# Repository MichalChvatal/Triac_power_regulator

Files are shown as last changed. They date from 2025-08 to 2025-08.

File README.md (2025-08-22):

# AVR Triac Regulator (ATtiny13)

---

## ⚠️ Safety Disclaimer

This project involves **AC mains voltage**, which is **extremely dangerous** and can cause **serious injury or death**.  

By using this project, you accept **full responsibility** for any accidents, injuries, or damages. The author is **not liable** for any consequences resulting from its use.  

**Important Safety Guidelines:**
- Always use insulated tools and protective equipment.
- Work with a qualified professional if you are inexperienced with mains circuits.
- Use galvanic isolation (optotriacs/optocouplers) wherever possible.
- **Do not proceed** if you are unfamiliar with handling high voltage.

---

## Project Overview

This project implements a **power regulator for universal commutator motors** (motors with brushes) and resistive loads (e.g., light bulbs and heating elements) using the **ATtiny13** microcontroller.  
It provides **0–100% power control** through **phase-angle control of a triac** with **AC mains zero-cross detection**.

⚠️ **Warning:** The circuit connects directly to **230 V mains**. Extreme caution is required during assembly and testing.

---

## ✨ Features
- Measurement of the delay between zero-crossing and triac triggering.
- Adjustable firing angle using a potentiometer (or DIP switch).
- Generation of a trigger pulse for the optotriac in every half cycle.
- Motor power control from **fully OFF (0%)** to **fully ON (100%)**.

---

## 🧩 Components

### Triac driver (optotriac)
Must be of the **random-phase type** (no built-in zero-cross detection), e.g.:
- `MOC3021`
- `MOC3010`

### Zero-cross detector
The output must be a **rectangular pulse signal** for reliable edge detection by the MCU, e.g.:
- `H11L1` (recommended)

If using slower optocouplers such as `4N35`, you must add a **Schmitt trigger** circuit to clean up the signal.

### Microcontroller
- `ATtiny13` (or alternatively `ATmega8`)

### Firing angle adjustment
- **Potentiometer** (connected to ADC input)  
- or **DIP switch** (digital inputs)

---

## ⚡ Safety notes
- This regulator is suitable only for **universal commutator motors (brush motors)** and **resistive loads** (e.g., light bulbs and heating elements).
- It is **not suitable for asynchronous (induction) motors**.  
- The motor must **not** have its own built-in electronic regulation.  
- The motor must use **series excitation**.

---

## 🛠️ Project directory structure

- **HW/** – Eagle PCB design files (.sch, .brd)
- **SW/**  - Atmel Studio project files (.cproj, .atsln), Doxyfile
  - **src/** – Source files (.c)
  - **inc/** – Header files (.h)
  - **docs/** – Generated documentation (Doxygen)

---

## ⚙️ Fuse and clock configuration

- Set fuses for **internal oscillator 4.8 MHz**:  
  - **Low fuse:** `0x79`  
  - **High fuse:** `0xFF`  
- ⚠️ **Calibration is required** – see ATtiny13 datasheet for details.  
- Note: `clk I/O` = `clk CPU`. The difference is that during sleep mode, **I/O clocks are disabled**, while CPU/peripheral clocks may continue to run.

--- 

## 🔧 Building the Project
To build the project, launch the **Regulator.atsln** file with **Microchip Studio (version 7.0.2594)**.

- From the menu bar, select Build > Build Solution.
-  Alternatively, use the shortcut F7.

The output files will be located in the project's **Debug** or **Release** folder.

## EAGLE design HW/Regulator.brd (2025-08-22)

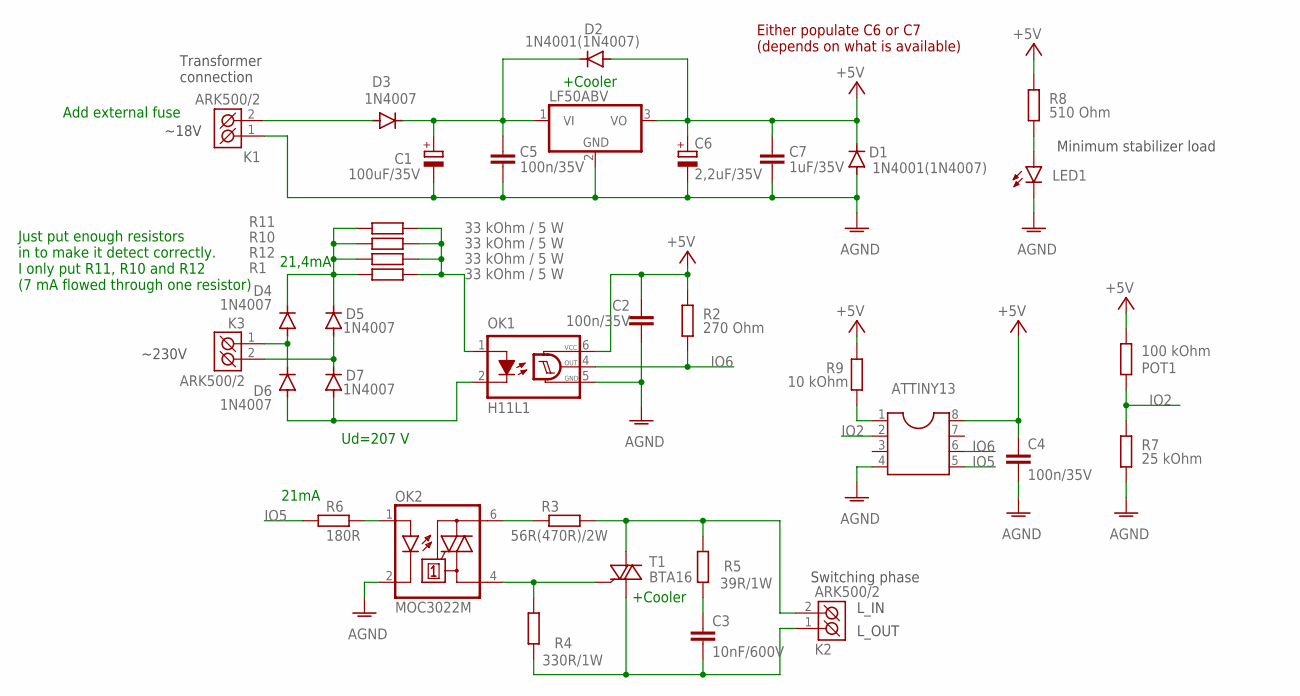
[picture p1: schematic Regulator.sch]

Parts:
ATTINY13: DIL8S; SOCKET-08
C1: 100uF/35V; E3,5-8
C2, C4, C5: 100n/35V; C050-025X075
C3: 10nF/600V; C025-030X050
C6: 2,2uF/35V; E2-4
C7: 1uF/35V; C050-025X075
D1, D2: 1N4001(1N4007); DO41-7.6
D3, D4, D5, D6, D7: 1N4007; DO41-7.6
K1, K2, K3: ARK500/2
LED1: LED5MM
OK1: H11L1; DIL06
OK2: MOC3022M; DIL06
POT1: 100 kOhm; 0207/10
R1, R10, R11, R12: 33 kOhm / 5 W; 0617V
R2: 270 Ohm; 0207/10
R3: 56R(470R)/2W; 0411/15
R4: 330R/1W; 0411/15
R5: 39R/1W; 0411/15
R6: 180R; 0207/10
R7: 25 kOhm; 0207/10
R8: 510 Ohm; 0207/10
R9: 10 kOhm; 0207/10
ST1: LF50ABV; TO220V
T1: BTA16; TO220BV

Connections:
+5V: ATTINY13.8, C2.1, C4.1, C6.+, C7.1, D1.C, D2.A, OK1.6 (VCC), POT1.1, R2.1, R8.1, R9.1, ST1.3 (VO)
AGND: ATTINY13.4, C1.-, C2.2, C4.2, C5.2, C6.-, C7.2, D1.A, K1.1 (K1), LED1.K (C), OK1.5 (GND), OK2.2 (C), R7.2, ST1.2 (GND)
IO2: ATTINY13.2, POT1.2, R7.1
IO5: ATTINY13.5, R6.1
IO6: ATTINY13.6, OK1.4 (OUT), R2.2
L_IN: K2.2 (K2), R3.2, R5.2, T1.T2 (A2)
L_OUT: C3.2, K2.1 (K1), R4.1, T1.T1 (A1)
unnamed: OK1.1 (A), R1.2, R10.2, R11.2, R12.2
unnamed: D4.A, D6.C, K3.1 (K1)
unnamed: LED1.A, R8.2
unnamed: D3.A, K1.2 (K2)
unnamed: OK2.6 (A2), R3.1
unnamed: D6.A, D7.A, OK1.2 (C)
unnamed: D5.A, D7.C, K3.2 (K2)
unnamed: C1.+, C5.1, D2.C, D3.C, ST1.1 (VI)
unnamed: OK2.1 (A), R6.2
unnamed: C3.1, R5.1
unnamed: OK2.4 (A1), R4.2, T1.G
unnamed: ATTINY13.1, R9.2
unnamed: D4.C, D5.C, R1.1, R10.1, R11.1, R12.1

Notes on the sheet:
Add external fuse
+Cooler
21mA
21,4mA
Either populate C6 or C7 (depends on what is available)
Minimum stabilizer load
L_IN
L_OUT
~18V
Switching phase
Transformer connection
~230V
Ud=207 V
Just put enough resistors in to make it detect correctly. I only put R11, R10 and R12 (7 mA flowed through one resistor)

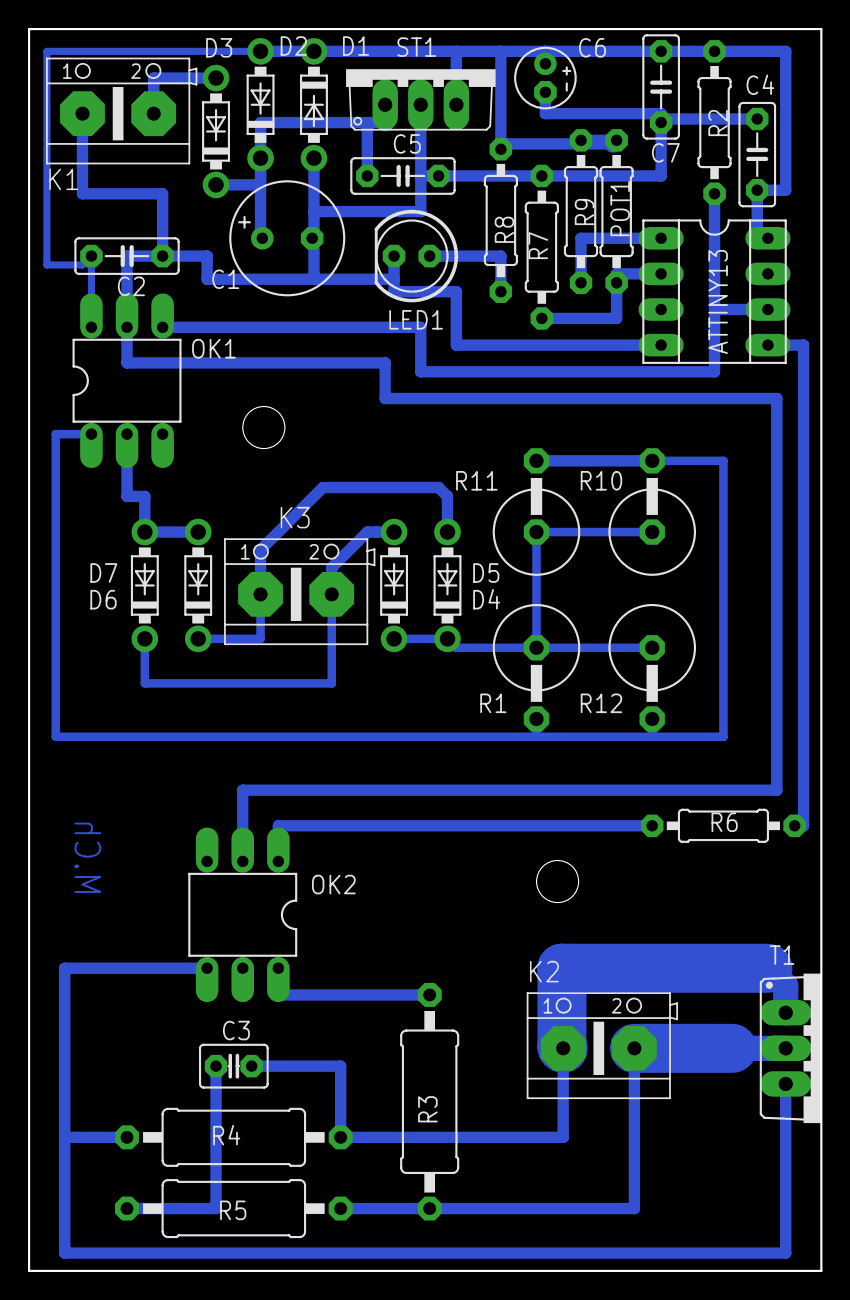
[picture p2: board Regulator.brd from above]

Board: 2 copper layers, 56.5 x 88.6 mm, 36 parts (0 on the bottom side), 20 nets.

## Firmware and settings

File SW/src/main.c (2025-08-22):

/*
 * Copyright (c) 2025, Michal Chvatal
 * All rights reserved.
 *
 * This source code is licensed under the BSD 3-Clause License found in the
 * LICENSE file in the root directory of this source tree.
 */ 

// Includes
#include <avr/io.h>
#include <avr/interrupt.h>
#include "functions.h"
	
/// Global ADC result value
volatile int ADCResult = 0;

/// Current state of the controller
volatile controller_states state = WAITING_FOR_TRIGGER;

/**
 * @brief Main program loop.
 * 
 * Initializes peripherals, enables interrupts, and starts ADC.  
 * Then remains in an infinite loop (logic runs in ISRs).
 */
int main(void)
{
	// Initialization functions
	PinsInit();
	// Enable interrupts
	sei(); 
	// Initial start of ADC (also necessary when running in free running mode)
	// (in free running mode ADC then starts automatically)
	ADCStart();
	
    while (1) 
    {
	}
}

/**
 * @brief ISR for zero-cross detection (INT0).
 * 
 * Interrupt service routine executed on the rising edge of pin PB1 (i.e., at zero crossing of the mains voltage)
 *
 * - Turns OFF triac.  
 * - Sets timer based on ADC value.  
 * - Starts next ADC conversion.  
 */
ISR (INT0_vect) 
{
	OPTOTRIAC_OFF;
	// Start the timer (based on the ADC setting), then output a 250 µs trigger pulse on pin PB1
	SetWaitingPulse(CalculateADCValue((unsigned)ADCResult));
	state = WAITING_FOR_TRIGGER;
    // Change the detection variable – signals zero crossing in the main loop
    // Get a new value from the ADC (free running mode is not used to avoid continuous ADC ISR calls)
	ADCStart();
}

/**
 * @brief ISR for ADC conversion complete.
 * 
 * Interrupt service routine executed every time an ADC conversion completes on pin PB3 (ADC3)
 * 
 */
ISR (ADC_vect)
{
	// Read necessary values from ADCL and ADCH registers (note that the read order is important!! ADCL must be read first!)
    // ADCResult ranges from 0 to 1023 (0-5V)
	volatile int ADCTempResult = ADCL;
	ADCResult = (ADCH << 8) + ADCTempResult;
}

/**
 * @brief ISR for Timer0 Compare Match A.
 * 
 * - Generates triac trigger pulse.  
 * - Turns triac OFF after pulse duration.  
 */
ISR (TIM0_COMPA_vect){
	if(state == WAITING_FOR_TRIGGER)
	{
		// Here the the trigger pulse is set and state is changed  to SWITCHING
		OPTOTRIAC_ON;
		state = SWITCHING;
		// Set trigger pulse timing
		SetTimer(8, 149);
	}
	else if (state == SWITCHING)
	{
		// Here the trigger pulse is turned off
		OPTOTRIAC_OFF;
	}
}

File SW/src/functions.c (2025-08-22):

/*
 * Copyright (c) 2025, Michal Chvatal
 * All rights reserved.
 *
 * This source code is licensed under the BSD 3-Clause License found in the
 * LICENSE file in the root directory of this source tree.
 */ 

#include "functions.h"

/**
 * @brief Configure pin PB0 for optotriac output.
 * 
 * Sets pin 5 (PB0) as output and initializes the optotriac to OFF state.
 */
void OptotriacOutputInit(void)
{
	DDRB |= (1 << DDB0);
	OPTOTRIAC_OFF;
}

/**
 * @brief Initialize ADC for potentiometer on pin PB3 (ADC3).
 * 
 * - Disables digital input buffer for power saving.  
 * - Configures ADC3 channel.  
 * - Enables ADC and ADC interrupts.  
 */
void ADCInit(void) 
{
	// PIN PB3 is set as input after reset => DDR bit = 0 and pull-up resistor is disabled => PORT bit = 0
    // This is suitable, so leave it as is.
    // Disable digital input buffer on this pin (better for power consumption)
	DIDR0 |= (1 << ADC3D);
	// Select pin ADC3 (PB3) => MUX0 = 1 and MUX1 = 1, select Vcc as reference => REFS0 = 0, left adjust result disabled => ADLAR = 0
	ADMUX |= (1 << MUX0) | (1 << MUX1);
	// Enable ADC, enable auto-triggering, and enable interrupt for this peripheral
    // ADCSRA |= (1 << ADEN) | (1 << ADATE) | (1 << ADIE);
    // Enable ADC and enable interrupt for this peripheral
	ADCSRA |= (1 << ADEN) | (1 << ADIE);
	// ADCSRB - mode selection (free running mode — We leave it because 0 0 0 means free running mode)
			
	// If free running mode is enabled, the first conversion cycle must be started by setting ADSC = 1, which performs initialization, then we don't do it anymore
}

/**
 * @brief Configure pin for zero-cross detection of mains voltage.
 * 
 * Enables external interrupt on rising edge of PB1.
 */
void ZeroDetectorInputInit(void)
{
    // PIN PB1 is set as input after reset => DDR bit = 0 and pull-up resistor is disabled => PORT bit = 0
    // This is suitable, so leave it as is.
    // Configure interrupt for pin PB1 (INT0) on rising edge and enable it:
	MCUCR |= (1 << ISC00) | (1 << ISC01);  // ISC00 = 1 and ISC01 = 1 - sets interrupt on rising edge
	GIMSK |= (1 << INT0);				   // INT0 = 1 - enables external interrupt on pin PB1
}

/**
 * @brief Start the first ADC conversion.
 */
void ADCStart(void)
{
	// If free running mode is enabled, the first conversion cycle must be started by setting ADSC = 1,
    // as this performs initialization; after that, it runs automatically
	ADCSRA |= (1 << ADSC);
}

/**
 * @brief Initialize all necessary pins and peripherals.
 */
void PinsInit(void)
{
	OptotriacOutputInit();
	ZeroDetectorInputInit();
	ADCInit();
}

void TimerInit(void)
{
    // Set normal mode (i.e., OC0A pin is disconnected — this is the default setting in register TCCR0A, so no changes needed)

    // Selection of prescaler (CS00, CS01, CS02) and writing to the Output Compare Register (OCR0A) is done at run time!

    /*
     * Calculations:
     * Note - The timer is 8-bit, so the maximum value that can be written to OCR0A must be considered!! (i.e., 0xFF)
     * Desired timer time:
     * Timer clock frequency [Hz] = Input clock frequency [Hz] / Prescaler;
     * OCR0A = Timer clock frequency [Hz] * Desired time [s] - 1;
     * Desired time [s] = 1 / Desired frequency [Hz] = (OCR0A + 1) / Timer clock frequency [Hz];
     *
     * Values for 250 µs pulse (the duration of the trigger pulse sent to the optotriac)
     * I/O Clock frequency will be 4.8 MHz
     * Timer clock frequency [Hz] = 4,800,000 [Hz] / 8 = 600,000 [Hz];
     * OCR0A = 600,000 [Hz] * 0.000250 [s] - 1 = 149;
     * => For a 250 µs pulse, a prescaler of 8 and an OCR0A register value of 149 are required
     *
     * Notes on 4.8 MHz as clock source:
     * With prescaler 8, the maximum measurable time is 425 µs
     * With prescaler 64, the maximum measurable time is 3.4 ms
     * With prescaler 256, the maximum measurable time is 13.6 ms
	 */
	return;
}

/**
 * @brief Configure Timer0 with given prescaler and OCR0A value.
 * 
 * @param prescaler Timer prescaler (8, 64, 256).
 * @param OCValue OCR0A register value.
 */
void SetTimer(unsigned prescaler, char OCValue)
{
	// Disable interrupts of the running timer
	TIMER_INT_OFF;
	// Stop the running timer (reset the clock signal)
	TIMER_STOP;
	switch(prescaler){
		case 8:
			// Set the input clock (prescaler) to 8 (0 1 0) - this enables the timer function
            // With prescaler 8, the maximum measurable time is 425 µs
			TCCR0B |= (1 << CS01);
			break;
		case 64:
			// With prescaler 64, the maximum measurable time is 3.4 ms
            // Set the input clock (prescaler) to 64 (0 1 1) - this enables the timer function
			TCCR0B |= (1 << CS00) | (1 << CS01);
			break;
		case 256:
			// With prescaler 256, the maximum measurable time is 13.6 ms
            // Set the input clock (prescaler) to 256 (1 0 0) - this enables the timer function
			TCCR0B |= (1 << CS02);
			break;
	}
    // Clear interrupt flags
	TIFR0 |= (1 << OCF0A);
	// Set Output Compare Register (current timer value + desired value (e.g., 1ms) => 149)
	OCR0A = TCNT0 + OCValue;
	// Enable interrupt on output compare match
	TIMSK0 |= (1 << OCIE0A);
}

/**
 * @brief Configure delay and trigger pulse after zero-cross event.
 * 
 * @param percent Power level (0–100%). 0% = always off, 100% = always on.
 */
void SetWaitingPulse(unsigned percent)
{
	/* Calculations:
     * Maximum voltage 5 V
     * Minimum voltage 1 V
     * Range 4 V
     * 10% of range is 1.4 V
     * 90% of range is 4.6 V
     */
	
	if (percent == 100)
	{
		SetTimer(64, (char)ZERO_CROSS_DELAY_OCR0A_PRESC_64);
	}
	else if(percent == 0)
	{
        // Disable interrupts of the running timer
		TIMER_INT_OFF;
        // Stop the running timer (reset the clock signal)
		TIMER_STOP;
	}
	else
	{
        // Calculate delay time in microseconds
		// volatile unsigned timeDelay = HALF_PERIOD_DURATION_US - (((HALF_PERIOD_DURATION_US / 100) * percent) + ZERO_CROSS_DELAY_US);
		volatile unsigned timeDelay = ((unsigned)HALF_PERIOD_DURATION_US - ((((unsigned)HALF_PERIOD_DURATION_US / 100) * percent) + (unsigned)ZERO_CROSS_DELAY_US));
		if (timeDelay < 425)
		{
			SetTimer(8, CalculateRegisterValue(8, timeDelay));
		}
		else if(timeDelay < 3400)
		{
			SetTimer(64, CalculateRegisterValue(64, timeDelay));
		}
		else {
			SetTimer(256, CalculateRegisterValue(256, timeDelay));
		}
	}
}
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

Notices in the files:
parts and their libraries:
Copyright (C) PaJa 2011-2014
